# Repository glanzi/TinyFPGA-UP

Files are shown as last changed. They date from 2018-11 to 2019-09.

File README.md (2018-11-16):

# TinyFPGA-UP

The TinyFPGA UP board is a tiny FPGA board based on a ICE40UP5K-SG48 FPGA from Lattice.

This board is based on Luke Valenty's [TinyFPGA-BX](https://github.com/tinyfpga/TinyFPGA-BX) project.
The programming pins are compatible with Piotr Esden-Tempski's [iCEBreaker-bitsy](https://github.com/icebreaker-fpga/icebreaker) project.

WARNING: This is work in progress and not yet soldered nor tested!

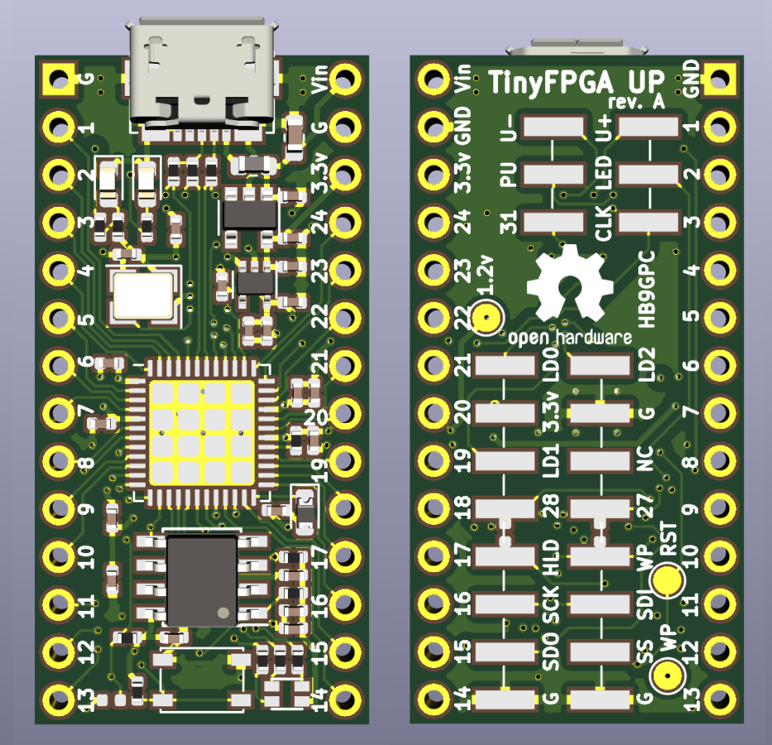
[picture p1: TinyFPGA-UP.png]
TinyFPGA UP board


## License
The TinyFPGA UP project is an open source project licensed under CERN Open Hardware Licence v1.2. Please see the included LICENSE file for details. If you do wish to distribute boards derived from this open source hardware project then you must also release the source files for the boards under CERN Open Hardware Licence v1.2. You are free to do this, but please improve upon the original design and provide a tangible benefit for users of the board.

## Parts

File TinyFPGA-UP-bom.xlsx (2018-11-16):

Qty | Ref | MPN | Desc | Digi-Key | Mouser
1 | U1 | ICE40UP5K-SG48I | FPGA | 220-2212-1-ND
1 | U2 | MIC5504-3.3YM5-TR | 3.3v LDO | 576-4764-1-ND
1 | U3 | DSC6001CI2A-016.0000 | 16Mhz Clock | DSC6001CI2A-016.0000-ND
1 | U4 | MIC5365-1.2YC5-TR | 1.2v LDO | 576-3175-1-ND‎
1 | U5 | AT25SF081-SSHD-B | 4MBit SPI Flash | 1265-1176-5-ND
1 | J3 | 10118192-0001LF | USB Micro Connector | 609-4613-1-ND
1 | D4 | LTST-C19HE1WT | Led RGB | 160-2162-1-ND
1 | SW1 | PTS810 SJM 250 SMTR LFS | Reset/Program Button | CKN10502CT-ND
1 | L1 | BLM18PG300SN1D | Ferrite Bead, 30ohm@100MHz impedance, 50mOhm DC resistance , 0603 | 490-1035-1-ND
1 | D1 |  | Led Green, 0603
1 | D2 |  | Led Red, 0603
1 | D3 | CDSU4148 | Diode 75V 150MA 0603 (CDSU4148 or CDBU0520) | 641-1001-1-ND
1 | C17 |  | 10uF Ceramic Capacitor, 6.3V, X5R, 20%, 0603 | 1276-6775-1-ND‎
1 | C6 |  | 10uF Ceramic Capacitor, 6.3V, X5R, 20%, 0402 | 490-13211-1-ND‎
8 | C1, C2, C3, C4, C13, C19, C20, C21 |  | 1uF Ceramic Capacitor, 10V, X7R, 10%, 0402 | 587-2477-1-ND‎
8 | C5, C7, C8, C9, C14, C15, C16, C18 |  | 100nF Ceramic Capacitor, 25V, X5R, 10%, 0402 (0.1uF) | 1276-1001-1-ND‎
4 | C10, C11, C12, C22 |  | 10nF Ceramic Capacitor, 50V X7R, 10%, 0402 (10000pF) | 490-6043-1-ND‎
1 | R1 |  | 1.5k resistor, 1% tolerance, 1/16 watt, 0402 | P1.50KLCT-ND
2 | R2, R3 |  | 68ohm resistor, 1% tolerance, 1/10 watt, 0402 | P68.0LCT-ND
1 | R4 |  | 100ohm resistor, 1% tolerance, 1/10 watt | P100LCT-ND
4 | R5, R6, R7, R10 |  | 10k resistor, 1% tolerance, 1/16 watt, 0402 | P10.0KLCT-ND
1 | R8 |  | 2.2k, 0402 (spez.) | P2.20KLCT-ND
4 | R9, R12, R13, R14 |  | 1k resistor, 1% tolerance, 1/16 watt, 0402 | P1.00KLCT-ND
1 | R11 |  | 0ohm resistor, bridge, 1/10 watt, 0402 | P0.0JCT-ND
 | R15, R16, R17 |  | DNP

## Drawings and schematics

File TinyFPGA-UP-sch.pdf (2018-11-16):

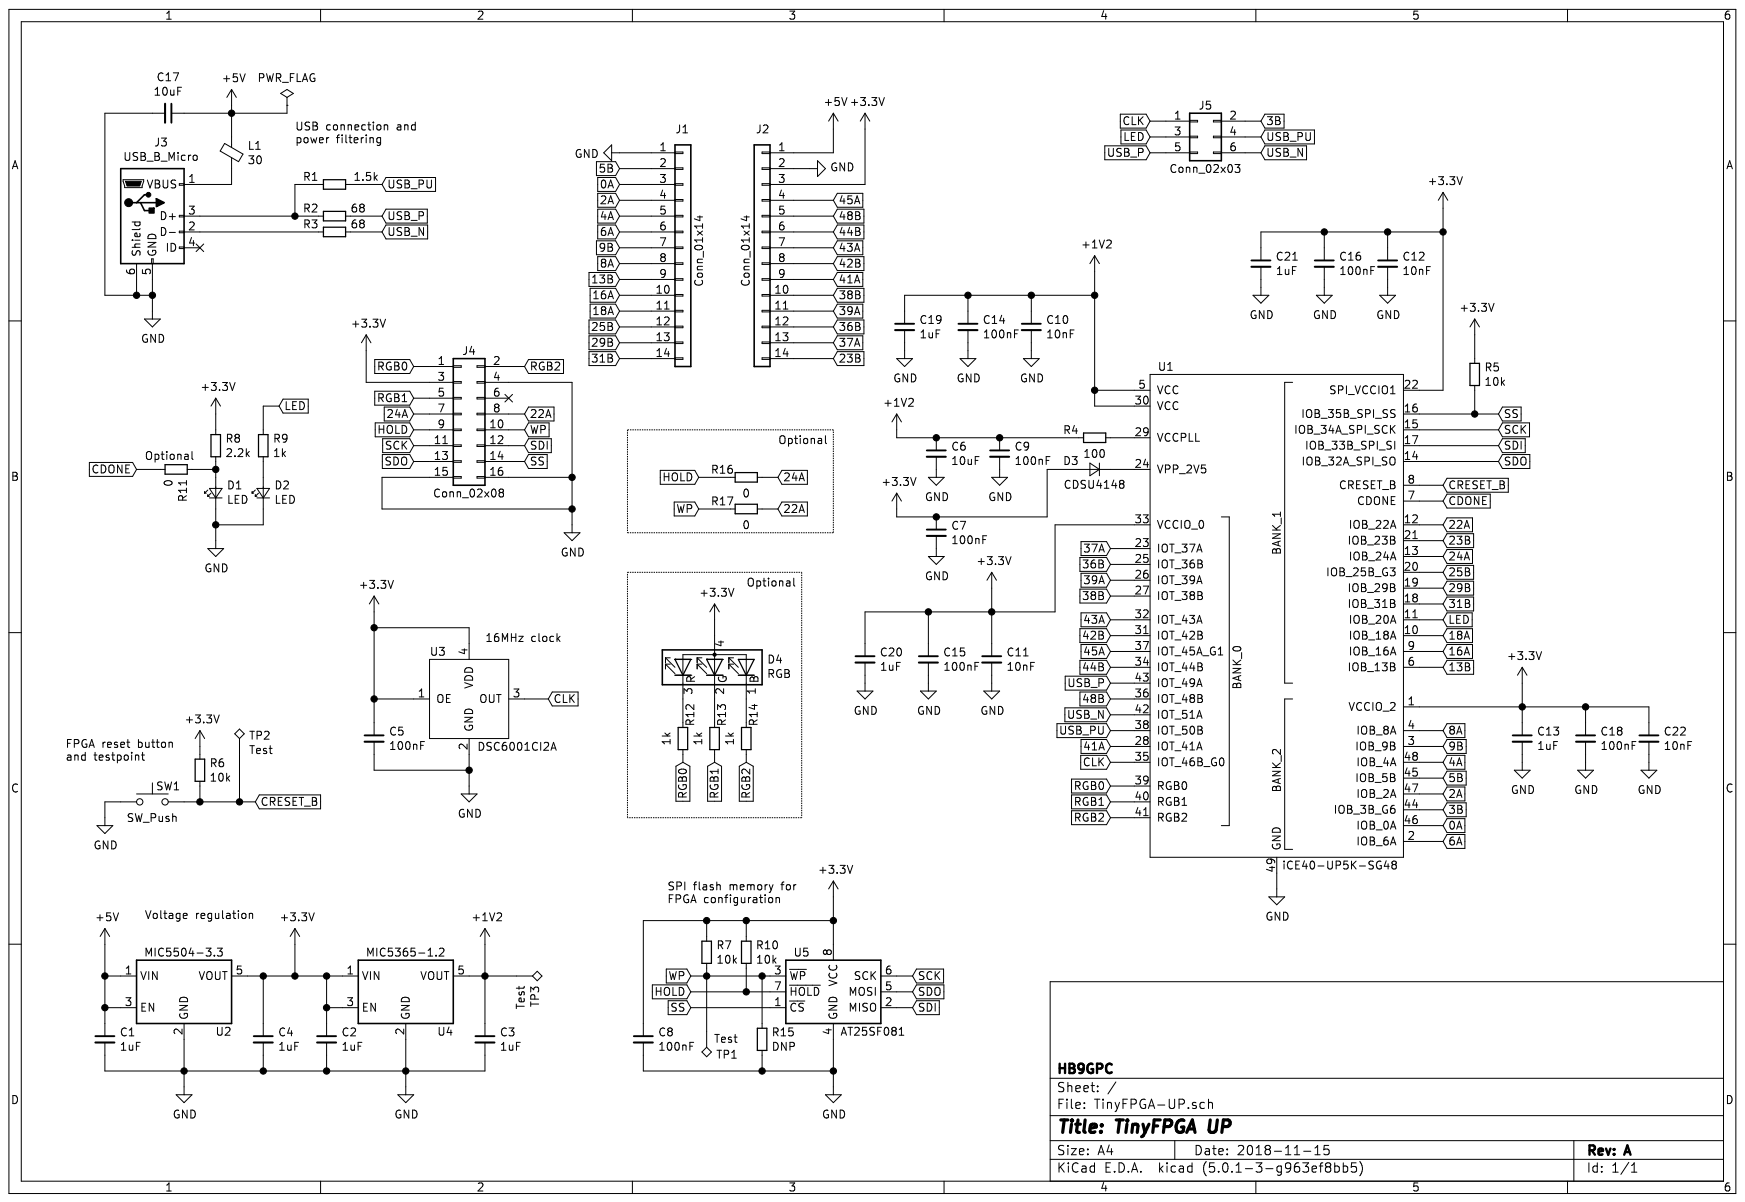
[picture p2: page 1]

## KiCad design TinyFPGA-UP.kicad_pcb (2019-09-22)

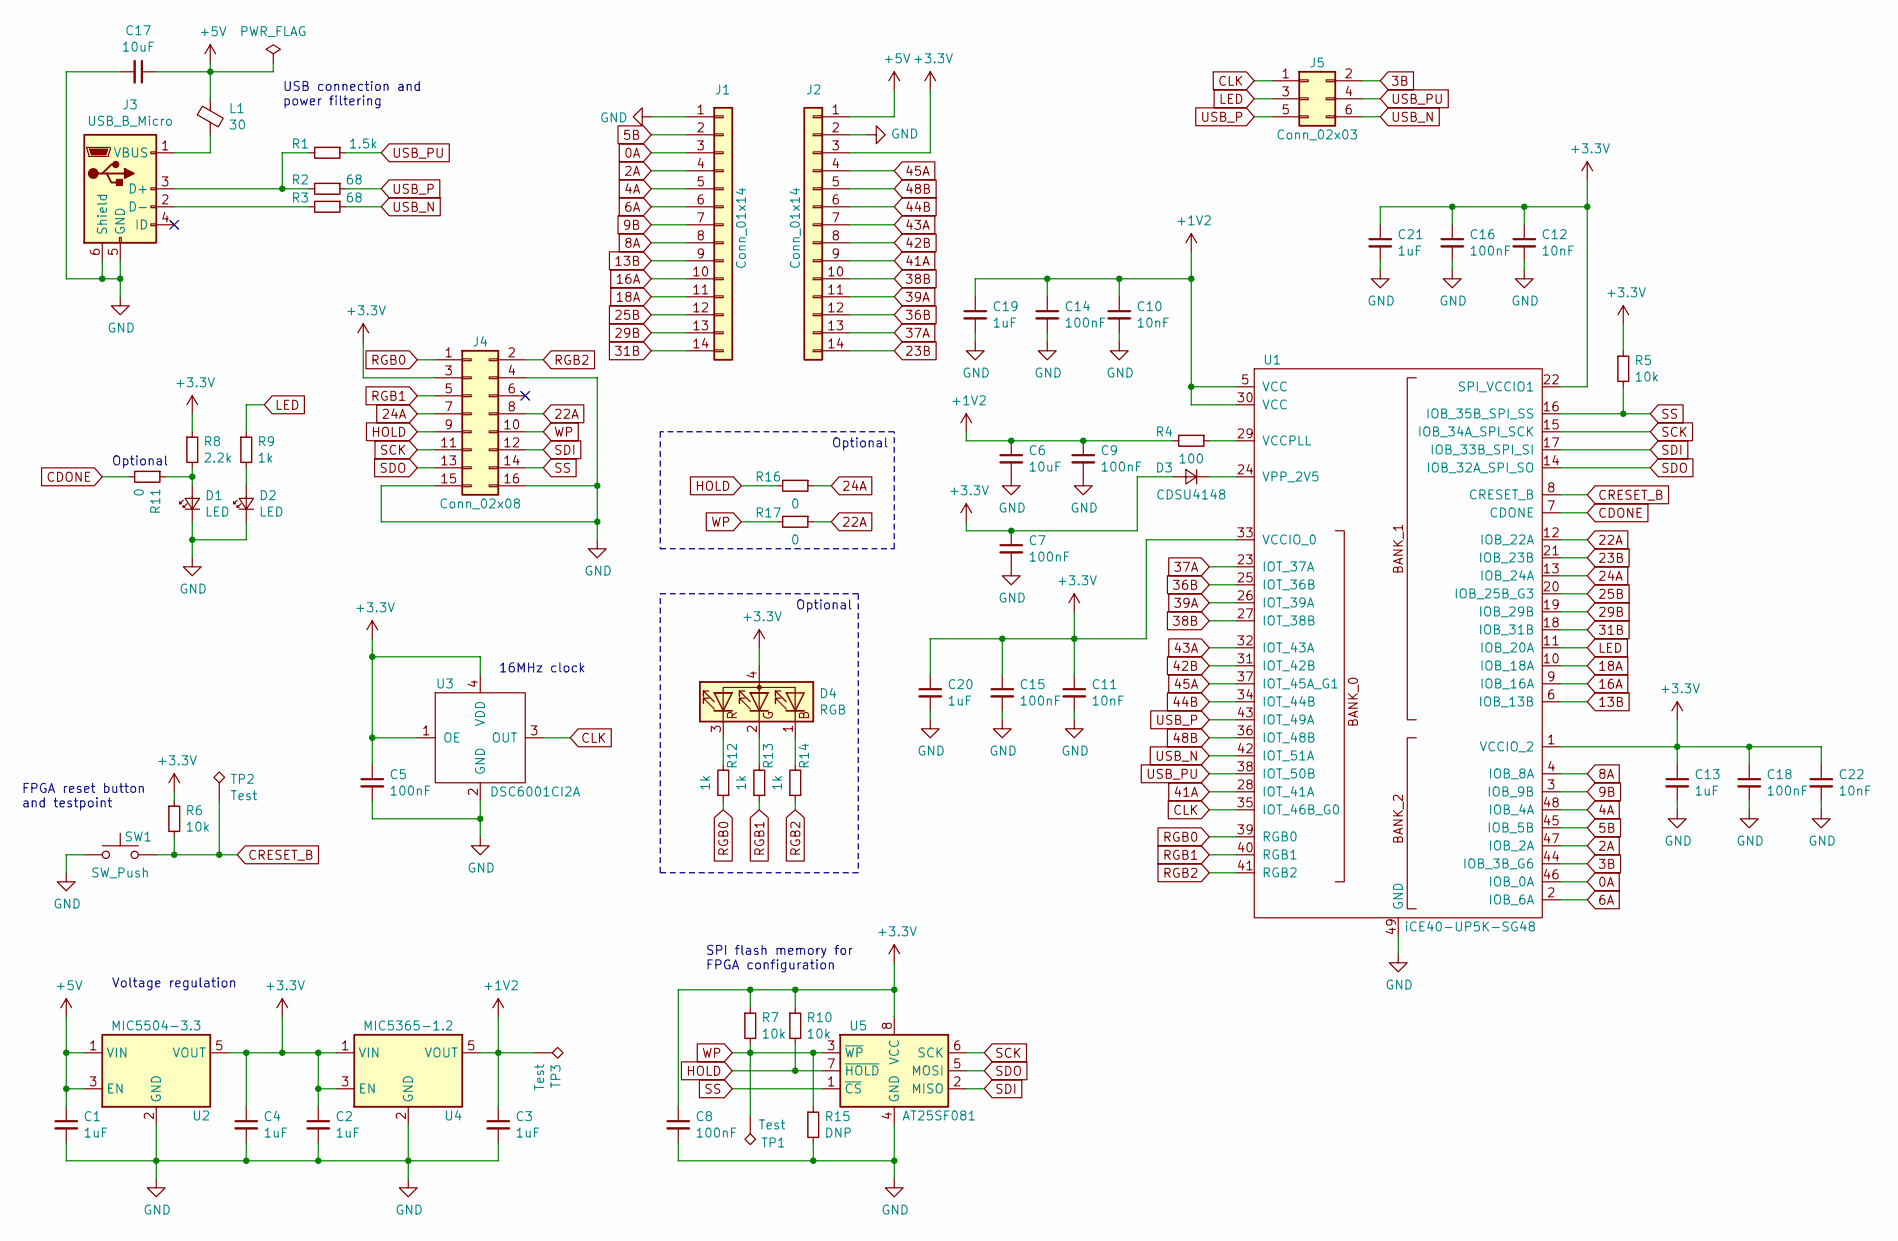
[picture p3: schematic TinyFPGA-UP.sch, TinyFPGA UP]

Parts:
C1, C2, C3, C4, C13, C19, C20, C21: 1uF; C_0402_1005Metric
C5, C7, C8, C9, C14, C15, C16, C18: 100nF; C_0402_1005Metric
C6: 10uF; C_0402_1005Metric
C10, C11, C12, C22: 10nF; C_0402_1005Metric
C17: 10uF; C_0603_1608Metric
D1, D2: LED; LED_0603_1608Metric
D3: CDSU4148; D_0603_1608Metric
D4: RGB; LTST-C19HE1WT
J1, J2: Conn_01x14; PinHeader_1x14_P2.54mm_Vertical
J3: USB_B_Micro; USB_Micro-B_Molex_47346-0001
J4: Conn_02x08; PinHeader_2x08_P2.54mm_Vertical_SMD
J5: Conn_02x03; PinHeader_2x03_P2.54mm_Vertical_SMD
L1: 30; L_0603_1608Metric
R1: 1.5k; R_0402_1005Metric
R2, R3: 68; R_0402_1005Metric
R4: 100; R_0402_1005Metric
R5, R6, R7, R10: 10k; R_0402_1005Metric
R8: 2.2k; R_0402_1005Metric
R9, R12, R13, R14: 1k; R_0402_1005Metric
R11, R16, R17: 0; R_0402_1005Metric
R15: DNP; R_0402_1005Metric
SW1: SW_Push; SW_SPST_PTS810
TP1, TP2, TP3: Test; TestPoint_Pad_D1.5mm
U1: iCE40-UP5K-SG48; QFN-48-1EP_7x7mm_P0.5mm_EP5.6x5.6mm
U2: MIC5504-3.3; SOT-23-5
U3: DSC6001CI2A; Crystal_SMD_3225-4Pin_3.2x2.5mm
U4: MIC5365-1.2; SOT-353_SC-70-5
U5: AT25SF081; SOIC-8_3.9x4.9mm_P1.27mm

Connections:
0A: J1.3, U1.46 (IOB_0A)
2A: J1.4, U1.47 (IOB_2A)
3B: J5.2, U1.44 (IOB_3B_G6)
4A: J1.5, U1.48 (IOB_4A)
5B: J1.2, U1.45 (IOB_5B)
6A: J1.6, U1.2 (IOB_6A)
8A: J1.8, U1.4 (IOB_8A)
9B: J1.7, U1.3 (IOB_9B)
13B: J1.9, U1.6 (IOB_13B)
16A: J1.10, U1.9 (IOB_16A)
18A: J1.11, U1.10 (IOB_18A)
22A: J4.8, R17.1, U1.12 (IOB_22A)
23B: J2.14, U1.21 (IOB_23B)
24A: J4.7, R16.1, U1.13 (IOB_24A)
25B: J1.12, U1.20 (IOB_25B_G3)
29B: J1.13, U1.19 (IOB_29B)
31B: J1.14, U1.18 (IOB_31B)
36B: J2.12, U1.25 (IOT_36B)
37A: J2.13, U1.23 (IOT_37A)
38B: J2.10, U1.27 (IOT_38B)
39A: J2.11, U1.26 (IOT_39A)
41A: J2.9, U1.28 (IOT_41A)
42B: J2.8, U1.31 (IOT_42B)
43A: J2.7, U1.32 (IOT_43A)
44B: J2.6, U1.34 (IOT_44B)
45A: J2.4, U1.37 (IOT_45A_G1)
48B: J2.5, U1.36 (IOT_48B)
+1V2: C3.1, C6.1, C9.1, C10.1, C14.1, C19.1, R4.2, TP3.1, U1.5 (VCC), U1.30 (VCC), U4.5 (VOUT)
+3V3: C2.1, C4.1, C5.1, C7.1, C8.1, C11.1, C12.1, C13.1, C15.1, C16.1, C18.1, C20.1, C21.1, C22.1, D3.2 (A), D4.4 (A), J2.3, J4.3, R5.1, R6.1, R7.1, R8.1, R10.1, U1.1 (VCCIO_2), U1.22 (SPI_VCCIO1), U1.33 (VCCIO_0), U2.5 (VOUT), U3.1 (OE), U3.4 (VDD), U4.1 (VIN), U4.3 (EN), U5.8 (VCC)
+5V: C1.1, C17.1, J2.1, L1.1, U2.1 (VIN), U2.3 (EN)
CDONE: R11.2, U1.7 (CDONE)
CLK: J5.1, U1.35 (IOT_46B_G0), U3.3 (OUT)
CRESET_B: R6.2, SW1.2, TP2.1, U1.8 (CRESET_B)
GND: C1.2, C2.2, C3.2, C4.2, C5.2, C6.2, C7.2, C8.2, C9.2, C10.2, C11.2, C12.2, C13.2, C14.2, C15.2, C16.2, C17.2, C18.2, C19.2, C20.2, C21.2, C22.2, D1.1 (K), D2.1 (K), J1.1, J2.2, J3.5 (GND), J3.6 (Shield), J4.4, J4.15, J4.16, R15.2, SW1.1, U1.49 (GND), U2.2 (GND), U3.2 (GND), U4.2 (GND), U5.4 (GND)
HOLD: J4.9, R10.2, R16.2, U5.7 (~HOLD)
LED: J5.3, R9.1, U1.11 (IOB_20A)
unnamed: D1.2 (A), R8.2, R11.1
unnamed: D2.2 (A), R9.2
unnamed: D3.1 (K), U1.24 (VPP_2V5)
unnamed: D4.1 (BK), R14.2
unnamed: D4.2 (GK), R13.2
unnamed: D4.3 (RK), R12.2
unnamed: J3.1 (VBUS), L1.2
unnamed: J3.2 (D-), R3.2
unnamed: J3.3 (D+), R1.2, R2.2
unnamed: R4.1, U1.29 (VCCPLL)
RGB0: J4.1, R12.1, U1.39 (RGB0)
RGB1: J4.5, R13.1, U1.40 (RGB1)
RGB2: J4.2, R14.1, U1.41 (RGB2)
SCK: J4.11, U1.15 (IOB_34A_SPI_SCK), U5.6 (SCK)
SDI: J4.12, U1.17 (IOB_33B_SPI_SI), U5.2 (MISO)
SDO: J4.13, U1.14 (IOB_32A_SPI_SO), U5.5 (MOSI)
SS: J4.14, R5.2, U1.16 (IOB_35B_SPI_SS), U5.1 (~CS)
USB_N: J5.6, R3.1, U1.42 (IOT_51A)
USB_P: J5.5, R2.1, U1.43 (IOT_49A)
USB_PU: J5.4, R1.1, U1.38 (IOT_50B)
WP: J4.10, R7.2, R15.1, R17.2, TP1.1, U5.3 (~WP)

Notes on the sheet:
USB connection and power filtering
Voltage regulation
16MHz clock
SPI flash memory for FPGA configuration
FPGA reset button and testpoint
Optional

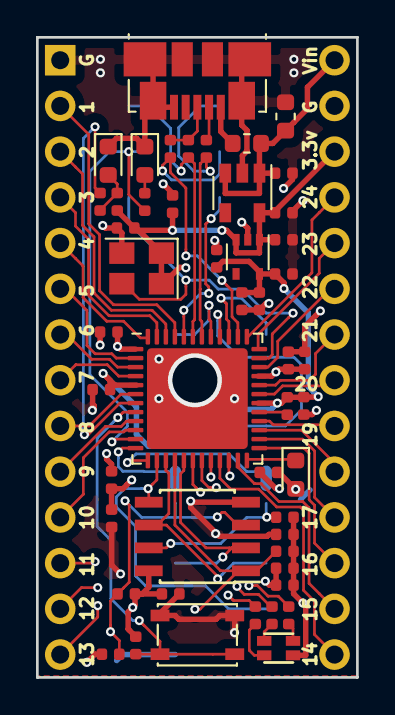
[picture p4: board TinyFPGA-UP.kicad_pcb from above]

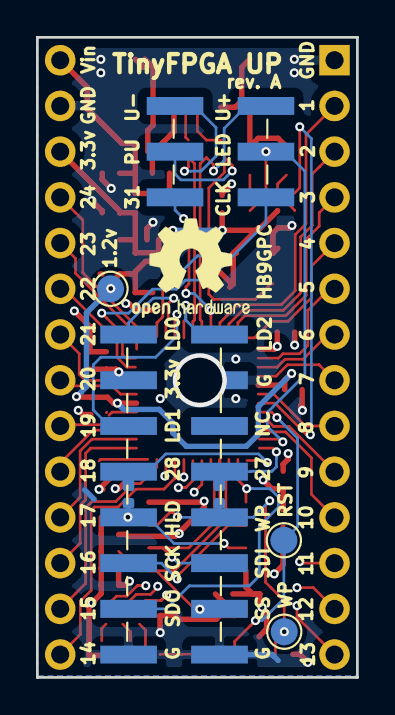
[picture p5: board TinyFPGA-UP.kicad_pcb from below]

Board: 4 copper layers, 17.8 x 35.6 mm, 58 parts (7 on the bottom side), 57 nets.

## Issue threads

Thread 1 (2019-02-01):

wfm?

peepo, 2019-02-01:
assembled?
redesigned?
abandoned?

tx!

keesj, 2019-02-02:
Hi,

The last pcb got lost and I ordered new one from oshpark. Meanwhile playing with migen!

peepo, 2019-09-25:
yup, how is progress?

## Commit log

2018-11-15 Update routing
    [TinyFPGA-UP.kicad_pcb, TinyFPGA-UP.sch]
2018-11-16 Make LED, WP, HLC compatible
    [TinyFPGA-UP.kicad_pcb, TinyFPGA-UP.sch]
2018-11-16 Adding plots
    [TinyFPGA-UP-B.Cu.gbl, TinyFPGA-UP-B.Mask.gbs, TinyFPGA-UP-B.SilkS.gbo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]
2018-11-16 Add BOM
    [TinyFPGA-UP-bom.xlsx]
2018-11-16 Minor changes
    [TinyFPGA-UP-B.Cu.gbl, TinyFPGA-UP-B.Mask.gbs, TinyFPGA-UP-B.SilkS.gbo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]
2018-11-16 Add comments
    [TinyFPGA-UP-B.Cu.gbl, TinyFPGA-UP-B.Mask.gbs, TinyFPGA-UP-B.SilkS.gbo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]
2018-11-17 Fix Pads Mask Clearance
    [TinyFPGA-UP-B.Cu.gbl, TinyFPGA-UP-B.Mask.gbs, TinyFPGA-UP-B.SilkS.gbo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]
2019-09-22 Simplify hand soldering
    [TinyFPGA-UP-B_Cu.gbl, TinyFPGA-UP-B_Mask.gbs, TinyFPGA-UP-B_SilkS.gbo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]
2019-09-22 Remove old plots
    [TinyFPGA-UP-B.Cu.gbl, TinyFPGA-UP-B.Mask.gbs, TinyFPGA-UP-B.SilkS.gbo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]
